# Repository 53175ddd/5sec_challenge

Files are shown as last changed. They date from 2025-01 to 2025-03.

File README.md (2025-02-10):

# 5sec_challenge

[#5sec_challenge](https://x.com/hashtag/5sec_challenge) とは：あなたの体内時計がどれほど正確か / いい加減かを試すことができる挑戦です

# 組み立て例

こんな感じに組み上がります．  
Arduino Nano は互換品を使っています．



# Booth 販売ページ

<https://nch-mosfet.booth.pm/items/6582794>

こんなのが届きます．



これに追加で，Arduino Nano をご用意下さい．Amazon で買える適当なもので大丈夫です．

# 簡易組み立て手順書

1. 部品をはんだ付けする
2. Arduino Nano にプログラムを書き込む
3. 組み上げる
4. 動かす

## 部品をはんだ付けする

基本的にフットプリントの通りのものをはんだ付けして行きます．  
向きは下の画像を参考にして下さい．C1 / C2 については，C1 が 104，C2 が 224 です．




## Arduino Nano にプログラムを書き込む

適合する USB ケーブルを使って PC に接続し，[5sec_challenge.ino](./5sec_challenge.ino) を書き込んで下さい．

## 組み上げる

トップ画像を参考に組み上げて下さい．スイッチを接続するかは任意です．

## 動かす

電源（USB または DC9 ~ 12V）を接続し，スイッチ（SW1）をぽちぽちしてください．結果が表示されます．  
その後，スイッチ（SW1）を押しながら Arduino Nano をリセットし，サブモードで起動させて下さい．スイッチを長押しして，タイムが常時表示されるようになれば動作確認完了です．

# 遊び方

友達や家族，知り合いなどと一緒に，誰が一番 5.000 秒に近いスコアを出せるかを勝負するもよし，一人で黙々とトライするもよし，9.999 秒までしか測れないストップウォッチとして使うもよし（？）  
結果はぜひ [#5sec_challenge](https://x.com/hashtag/5sec_challenge) を添えてツイートしてください．

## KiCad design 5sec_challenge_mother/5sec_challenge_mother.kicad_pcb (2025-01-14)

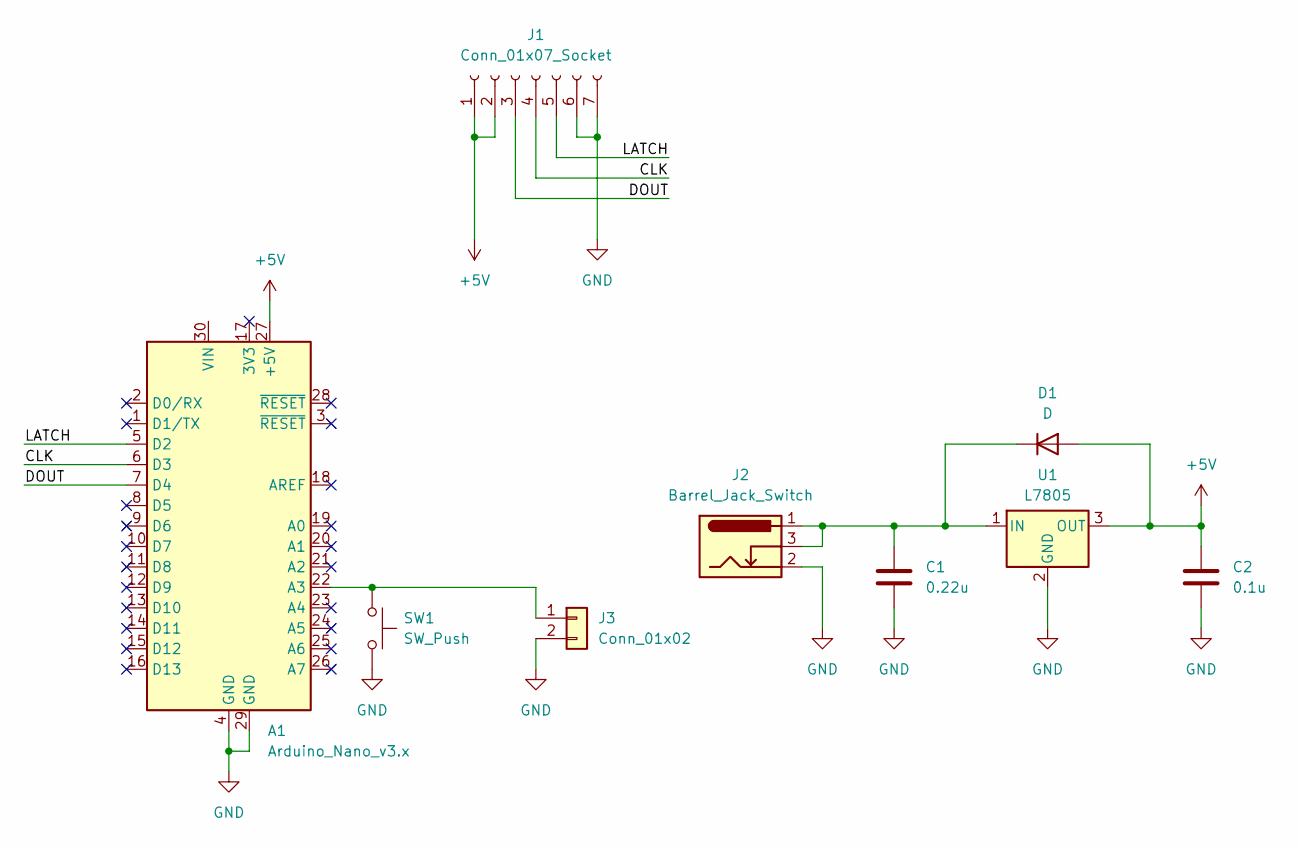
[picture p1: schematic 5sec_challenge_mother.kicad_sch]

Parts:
A1: Arduino_Nano_v3.x; Arduino_Nano
C1: 0.22u; C_Disc_D4.7mm_W2.5mm_P5.00mm
C2: 0.1u; C_Disc_D4.7mm_W2.5mm_P5.00mm
D1: D; D_A-405_P10.16mm_Horizontal
J1: Conn_01x07_Socket; PinSocket_1x07_P2.54mm_Vertical
J2: Barrel_Jack_Switch; BarrelJack_Horizontal
J3: Conn_01x02; JST_XH_B2B-XH-AM_1x02_P2.50mm_Vertical
SW1: SW_Push; SW_PUSH_6mm
U1: L7805; TO-220-3_Vertical

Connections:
+5V: A1.27 (+5V), C2.2, D1.2 (A), J1.1, J1.2, U1.3 (OUT)
/CLK: A1.6 (D3), J1.4
/DOUT: A1.7 (D4), J1.3
/LATCH: A1.5 (D2), J1.5
GND: A1.4 (GND), A1.29 (GND), C1.2, C2.1, J1.6, J1.7, J2.2, J3.2, SW1.2, U1.2 (GND)
unnamed: A1.22 (A3), J3.1, SW1.1
unnamed: C1.1, D1.1 (K), J2.1, J2.3, U1.1 (IN)

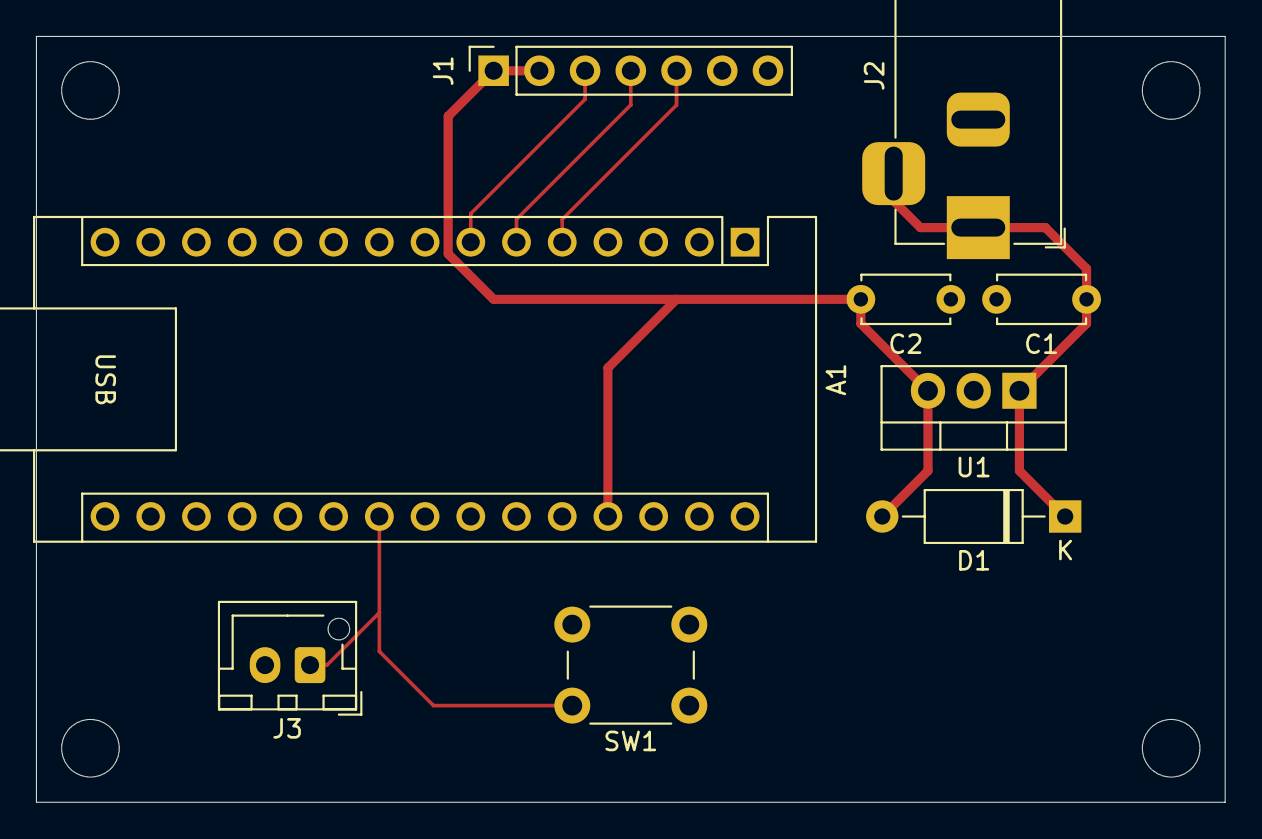
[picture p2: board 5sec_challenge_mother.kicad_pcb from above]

Board: 2 copper layers, 66.0 x 42.5 mm, 9 parts (0 on the bottom side), 7 nets.

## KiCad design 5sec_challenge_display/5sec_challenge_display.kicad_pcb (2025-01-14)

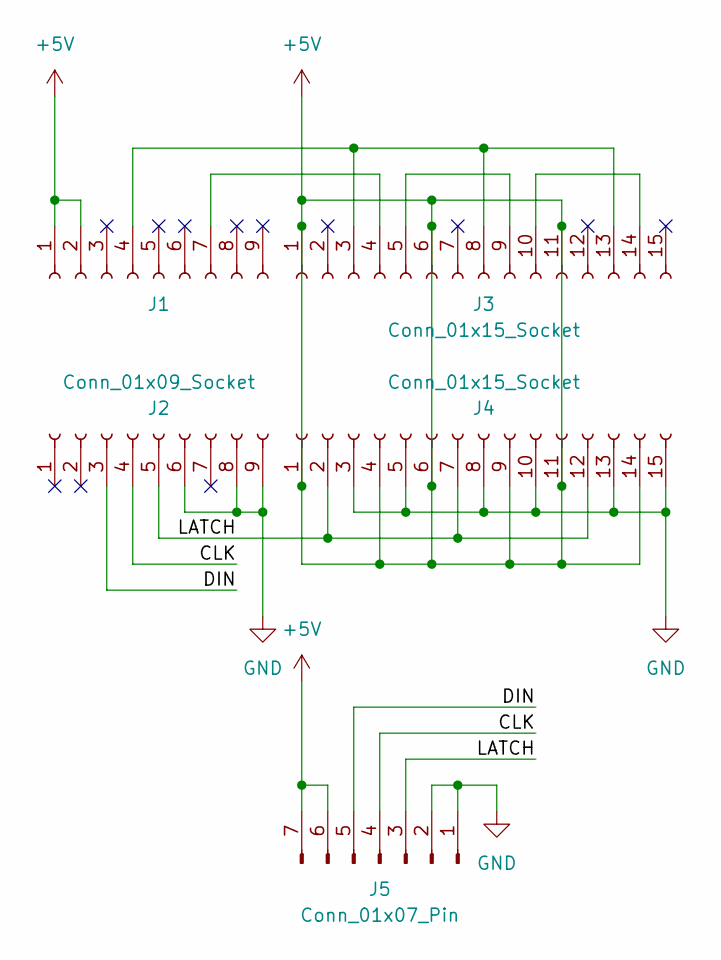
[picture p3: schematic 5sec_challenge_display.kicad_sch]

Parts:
J1, J2: Conn_01x09_Socket; PinSocket_1x09_P2.54mm_Vertical
J3, J4: Conn_01x15_Socket; PinSocket_1x15_P2.54mm_Vertical
J5: Conn_01x07_Pin; PinHeader_1x07_P2.54mm_Horizontal

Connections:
+5V: J1.1, J1.2, J3.1, J3.6, J3.11, J4.1, J4.4, J4.6, J4.9, J4.11, J4.14, J5.6, J5.7
/CLK: J2.4, J5.4
/DIN: J2.3, J5.5
/LATCH: J2.5, J4.2, J4.7, J4.12, J5.3
GND: J2.6, J2.8, J2.9, J4.3, J4.5, J4.8, J4.10, J4.13, J4.15, J5.1, J5.2
unnamed: J1.4, J3.3, J3.8, J3.13
unnamed: J1.7, J3.4
unnamed: J3.5, J3.9
unnamed: J3.10, J3.14

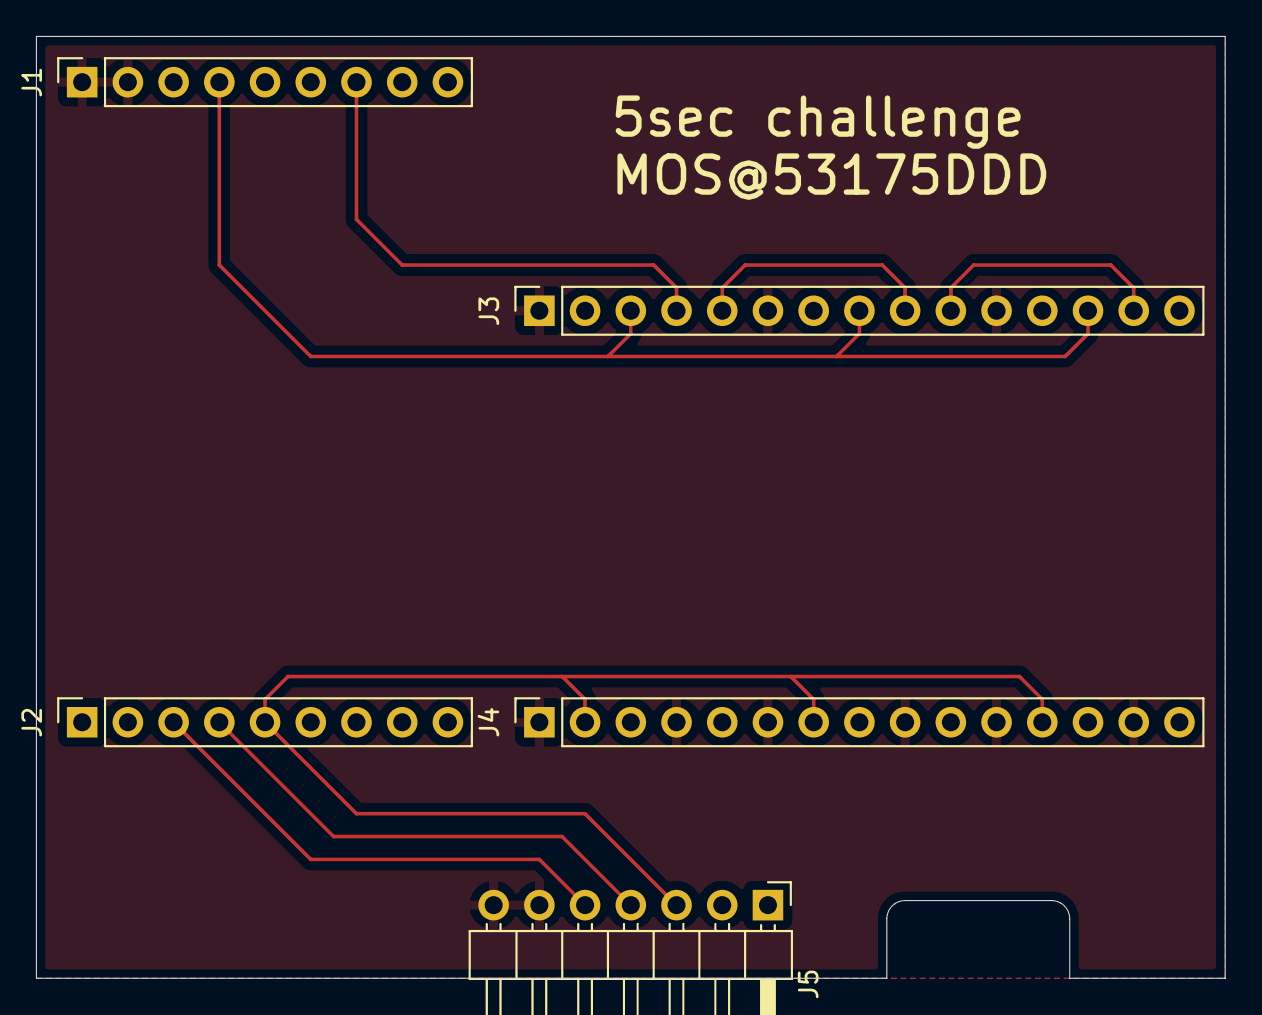
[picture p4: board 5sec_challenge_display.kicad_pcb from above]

Board: 2 copper layers, 66.0 x 52.3 mm, 5 parts (0 on the bottom side), 9 nets.

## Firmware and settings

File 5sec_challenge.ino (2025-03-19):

#define OFFSET 0  // クロックの誤差調整用 / 適宜調整 / わからなければ 0 でよし

#define SW A3

#define LATCH 2
#define DOUT  4
#define CLK   3

bool is_pressed = false;

uint16_t counter   = 0;
uint8_t  sw_status = 0;

uint8_t font[] = {0b11111100, 0b01100000, 0b11011010, 0b11110010, 0b01100110, 0b10110110, 0b10111110, 0b11100000, 0b11111110, 0b11110110};

ISR(TIMER1_COMPA_vect) {
  sw_status = (sw_status << 1) + ((digitalRead(SW) == 0) ? 1 : 0);  // D3 を読み取りステータス変数を更新

  if((sw_status & 0b00000011) == 0b01) {  // スイッチ押されたとき
    clear();  // ディスプレイの表示を消す
    counter = 1;
  }

  if(digitalRead(SW) == LOW) {   // スイッチが押されている間
    counter++;
    if(counter > 9999) {
      counter = 9999;
    }

    if(is_pressed) {
      output(counter);
    }
  }

  if((sw_status & 0b00000011) == 0b10) {  // スイッチ放されたとき
    output(counter);  // 結果を表示
  }
}

void setup() {
  pinMode(SW   ,  INPUT_PULLUP);
  pinMode(LATCH, OUTPUT);
  pinMode(DOUT , OUTPUT);
  pinMode(CLK  , OUTPUT);

  digitalWrite(LATCH, HIGH);

  digitalWrite(LATCH,  LOW);
  delayMicroseconds(10);
  shiftOut(DOUT, CLK, LSBFIRST, 0xff);
  shiftOut(DOUT, CLK, LSBFIRST, 0xff);
  shiftOut(DOUT, CLK, LSBFIRST, 0xff);
  shiftOut(DOUT, CLK, LSBFIRST, 0xff);
  delayMicroseconds(10);
  digitalWrite(LATCH, HIGH);

  delay(100);

  is_pressed = (digitalRead(SW) == LOW) ? true : false;

  delay(100);

  digitalWrite(LATCH,  LOW);
  delayMicroseconds(10);
  shiftOut(DOUT, CLK, LSBFIRST, 0x00);
  shiftOut(DOUT, CLK, LSBFIRST, 0x00);
  shiftOut(DOUT, CLK, LSBFIRST, 0x00);
  shiftOut(DOUT, CLK, LSBFIRST, 0x00);
  delayMicroseconds(10);
  digitalWrite(LATCH, HIGH);

  delay(100);

  digitalWrite(LATCH,  LOW);
  delayMicroseconds(10);
  shiftOut(DOUT, CLK, LSBFIRST, font[0]);
  shiftOut(DOUT, CLK, LSBFIRST, font[0]);
  shiftOut(DOUT, CLK, LSBFIRST, font[0]);
  shiftOut(DOUT, CLK, LSBFIRST, font[5] + 1);
  delayMicroseconds(10);
  digitalWrite(LATCH, HIGH);

  while(digitalRead(SW) == LOW);

  delay(10);

  TCCR1A = 0;                           // タイマー 1 動作モードを初期化
  TCCR1B = (1 << WGM12) | (1 << CS10);  // CTC モード 分周比 1
  OCR1A  = 16000 - 1 + OFFSET;          // 1kHz となるように設定
  TIMSK1 = (1 << OCIE1A);               // タイマー 1 の A マッチ割り込みを許可

  Serial.begin(115200);
}

void loop() {
}

void output(const uint16_t raw) {
  uint16_t counter = raw;
  int8_t a, b, c, d;

  d = counter % 10;
  counter = (counter - d) / 10;

  c = counter % 10;
  counter = (counter - c) / 10;

  b = counter % 10;
  counter = (counter - b) / 10;

  a = counter;

  digitalWrite(LATCH,  LOW);
  delayMicroseconds(10);
  shiftOut(DOUT, CLK, LSBFIRST, font[d]);
  shiftOut(DOUT, CLK, LSBFIRST, font[c]);
  shiftOut(DOUT, CLK, LSBFIRST, font[b]);
  shiftOut(DOUT, CLK, LSBFIRST, font[a] + 1);
  delayMicroseconds(10);
  digitalWrite(LATCH, HIGH);

  if(!is_pressed) {
    Serial.print(a);
    Serial.print(b);
    Serial.print(c);
    Serial.print(d);
    Serial.print(" ms\n");
  }
}

void clear(void) {
  digitalWrite(LATCH,  LOW);
  for(size_t i = 0; i < 4; i++) {
    shiftOut(DOUT, CLK, LSBFIRST, 0);
  }
  digitalWrite(LATCH, HIGH);
}

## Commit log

2025-01-10 Arduino プロジェクト作成
2025-01-10 コード整形
2025-01-11 KiCAD プロジェクト作成
    [5sec_challenge.kicad_pcb, 5sec_challenge.kicad_sch]
2025-01-13 一旦削除（作り直し）
    [5sec_challenge.kicad_pcb, 5sec_challenge.kicad_sch]
2025-01-13 KiCAD プロジェクト作り直し
    [5sec_challenge_display.kicad_pcb, 5sec_challenge_display.kicad_sch, 5sec_challenge_mother.kicad_pcb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]
2025-01-13 表示基板作成
    [5sec_challenge_display.kicad_pcb, 5sec_challenge_display.kicad_sch]
2025-01-14 基板外形調整
    [5sec_challenge_display.kicad_pcb]
2025-01-14 ガーバー出力
    [5sec_challenge_display.kicad_pcb, 5sec_challenge_mother.kicad_pcb]
2025-01-14 スイッチ付け忘れてたので追加
    [5sec_challenge_mother.kicad_sch]
2025-01-14 スイッチ追加
    [5sec_challenge_mother.kicad_pcb]
2025-01-28 ほぼ完成
2025-02-03 モード追加
    スイッチを押しながら起動するとモード切替
2025-03-19 起動時に 5.000 を表示するように変更
